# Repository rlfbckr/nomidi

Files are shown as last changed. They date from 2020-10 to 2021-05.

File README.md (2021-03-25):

# NOMIDI
**A [OSC](http://opensoundcontrol.org/) based performance controller**

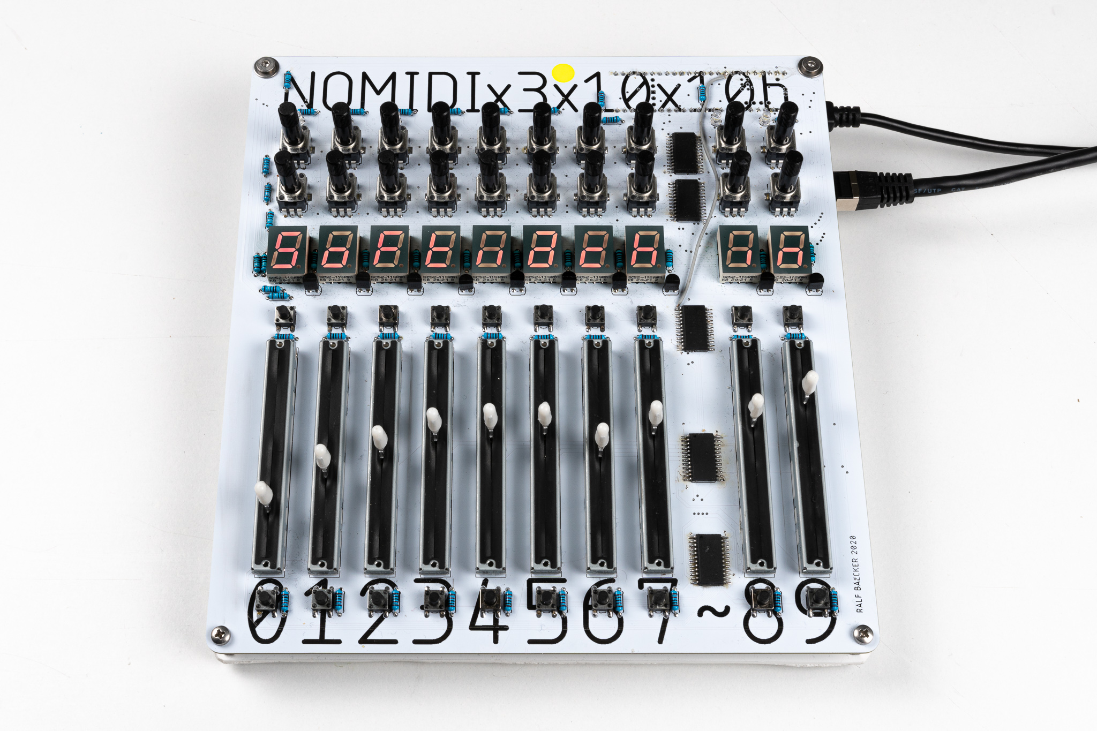
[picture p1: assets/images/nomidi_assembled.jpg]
NOMIDI Assembled


I build this controller out of frustration that [MIDI controllers](https://en.wikipedia.org/wiki/MIDI_controller) are still using only 7 bit resolution. **NOMIDI** is a OSC based controller with 10 channels each 10bit (12 or 14 bit should be possible as well) resolution for the sliders and knobs. The controller is based on a Teensy 4.1 microcontroller including a high speed ethernet port to broadcast and receive OSC to and from different nodes in the network.
 
**PLEAYSE NOTE:** NOMIDI is OSC based in cannot be used in an "MIDI Environment". I can send/reicive only signals form OSC enabled Software and Hardware. e.g. MaxMSP, Supercollider, PureData, Processing, OpenFrameworks, monome norns, Abelton Live and many more.

## Control elements
* inputs:
  - 10 x 2 knobs (potentiometer ALPS)
  - 10 x 2 pushbuttons
  - 10 x 1 slider (potentiometer 6mm ALPS)
* outputs: 
  - 10 x 1 seven-segment element (13,5mm)
  - 10 x 1 white led (3mm)

## Interface / Connection
- USB SlipSerial
**or**
- Ethernet

## PCB (Printed circuit board)
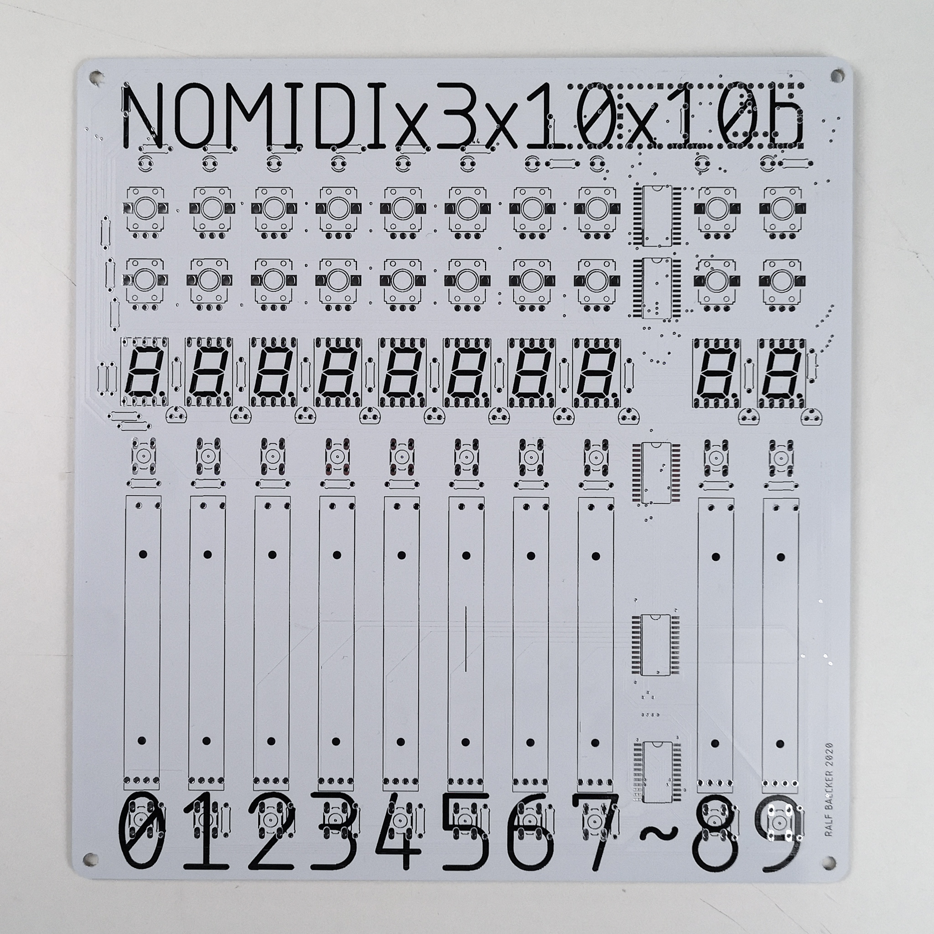
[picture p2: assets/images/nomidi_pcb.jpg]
NOMIDI PCB


## Software
*For flashing the firmware on the Teensy board these software compnents are needed:*

- Arduino IDE (Version 1.8.13) [(download)](https://www.arduino.cc/en/software)
- Teensyduino (Version 1.53) [(download)](https://www.pjrc.com/teensy/td_download.html)

## Required Arduino libraries
- OSCBundle  *[install via package manager]*
- Chrono  *[install via package manager]*
- MUX74HC4067 *[install via package manager]*
- SevSeg ( Seven Segment Multiplexing Library ) *[modefied version included in firmware sketch]*
- NativeEthernet ( Teensy 4.1 ) *[comes with teensyduino]*

## Bill of Materials
[BOM](https://docs.google.com/spreadsheets/d/1EoTag_wGxFKfiME3yydL2qvFMf1TQeLivOXvCBYUS_A/edit#gid=0)

## Firmware configuration

NOMIDI can communicate ether via *Ethernet* oder *Serial* (OSC over SLIPSerial). edit **firmware/nomidi_firmware/config.h**  

### Use Serial ( OSC over SLIP Serial) for communication:
```
#define USE_SLIP_SERIAL
```

### Use Ethernet ( OSC over UDP) for communication:
```
#define USE_ETHERNET

static byte mac[] = { 0xDE, 0xAD, 0xBE, 0xEF, 0xFC, 0x88}; // hardware addres of your device
static IPAddress myIP(10, 0, 0, 123); // ip address of the controller
static IPAddress serverIP(10, 0, 0, 3); // ip addres of your laptop
static int serverPort = 9013;
static int incommingPort = 10013;

```

## Teensy Settings
```
Borad:      Teensy 4.1
USB Type:   USB Serial
CPU Speed:  600 Mhz
```

## OSC messages

### NOMDI -> software

Potentiometer 1 (top row)
```
/nm/p0 [0-4095] [0-4095] [0-4095] [0-4095] [0-4095] [0-4095] [0-4095] [0-4095] [0-4095] [0-4095]
```
Potentiometer 0 (bottom row)
```
/nm/p1 [0-4095] [0-4095] [0-4095] [0-4095] [0-4095] [0-4095] [0-4095] [0-4095] [0-4095] [0-4095]
```
Button 1 (top row)
```
/nm/p1 [0/1] [0/1] [0/1] [0/1] [0/1] [0/1] [0/1] [0/1] [0/1] [0/1]
```
Fader
```
/nm/f [0-4095] [0-4095] [0-4095] [0-4095] [0-4095] [0-4095] [0-4095] [0-4095] [0-4095] [0-4095]
```
Button 0 (bottom row)
```
/nm/p0 [0/1] [0/1] [0/1] [0/1] [0/1] [0/1] [0/1] [0/1] [0/1] [0/1]
```

### software -> NOMIDI
LED (single)
```
/nm/setled <pos 0-9> <brightness 0-100>
```
7Segment (single segment)
```
/nm/set7set <pos 0-9> <character>
```

7Segment (all segments)
```
/nm/set7segall <character> <character> <character> <character> <character> <character> <character> <character> <character> <character>
```

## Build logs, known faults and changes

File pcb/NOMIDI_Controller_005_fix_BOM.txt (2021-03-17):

Partlist exported from C:/local/projekte/nomidi/eagle/NOMIDI_Controller_005_fix.sch at 2021-03-17 19:26

Part Value              Device             Package     Description                       MF MPN      OC_FARNELL OC_NEWARK POPULARITY SPICEPREFIX
D0                      7SEG-CK            7SEG-13     7-segment DISPLAY                                                  3                     
D1                      7SEG-CK            7SEG-13     7-segment DISPLAY                                                  3                     
D2                      7SEG-CK            7SEG-13     7-segment DISPLAY                                                  3                     
D3                      7SEG-CK            7SEG-13     7-segment DISPLAY                                                  3                     
D4                      7SEG-CK            7SEG-13     7-segment DISPLAY                                                  3                     
D5                      7SEG-CK            7SEG-13     7-segment DISPLAY                                                  3                     
D6                      7SEG-CK            7SEG-13     7-segment DISPLAY                                                  3                     
D7                      7SEG-CK            7SEG-13     7-segment DISPLAY                                                  3                     
D8                      7SEG-CK            7SEG-13     7-segment DISPLAY                                                  3                     
D9                      7SEG-CK            7SEG-13     7-segment DISPLAY                                                  3                     
IC1  4067D              4067D              SO24W       16-channel ANALOG MULTIPLEXER                                      0                     
IC2  4067D              4067D              SO24W       16-channel ANALOG MULTIPLEXER                                      0                     
IC3  4067D              4067D              SO24W       16-channel ANALOG MULTIPLEXER                                      0                     
IC4  4067D              4067D              SO24W       16-channel ANALOG MULTIPLEXER                                      0                     
IC5  4067D              4067D              SO24W       16-channel ANALOG MULTIPLEXER                                      0                     
LED0                    LED3MM             LED3MM      LED                                                                97                    
LED1                    LED3MM             LED3MM      LED                                                                97                    
LED2                    LED3MM             LED3MM      LED                                                                97                    
LED3                    LED3MM             LED3MM      LED                                                                97                    
LED4                    LED3MM             LED3MM      LED                                                                97                    
LED5                    LED3MM             LED3MM      LED                                                                97                    
LED6                    LED3MM             LED3MM      LED                                                                97                    
LED7                    LED3MM             LED3MM      LED                                                                97                    
LED8                    LED3MM             LED3MM      LED                                                                97                    
LED9                    LED3MM             LED3MM      LED                                                                97                    
M0   SLIDEPOT-ALPS-60MM SLIDEPOT-ALPS-60MM RS6011SP600                                                                                          
M1   SLIDEPOT-ALPS-60MM SLIDEPOT-ALPS-60MM RS6011SP600                                                                                          
MS0                     10-XX              B3F-10XX    OMRON SWITCH                         B3F-1000 176432     36M3542   72                    
MS1                     10-XX              B3F-10XX    OMRON SWITCH                         B3F-1000 176432     36M3542   72                    
MS2                     10-XX              B3F-10XX    OMRON SWITCH                         B3F-1000 176432     36M3542   72                    
MS3                     10-XX              B3F-10XX    OMRON SWITCH                         B3F-1000 176432     36M3542   72                    
MS4                     10-XX              B3F-10XX    OMRON SWITCH                         B3F-1000 176432     36M3542   72                    
MS5                     10-XX              B3F-10XX    OMRON SWITCH                         B3F-1000 176432     36M3542   72                    
MS6                     10-XX              B3F-10XX    OMRON SWITCH                         B3F-1000 176432     36M3542   72                    
MS7                     10-XX              B3F-10XX    OMRON SWITCH                         B3F-1000 176432     36M3542   72                    
MS8                     10-XX              B3F-10XX    OMRON SWITCH                         B3F-1000 176432     36M3542   72                    
MS9                     10-XX              B3F-10XX    OMRON SWITCH                         B3F-1000 176432     36M3542   72                    
P0_0 US-EVUF3A          US-EVUF3A          EVUF        9 mm Square Rotary Potentiometers                                  0                     
P0_1 US-EVUF3A          US-EVUF3A          EVUF        9 mm Square Rotary Potentiometers                                  0                     
P0_2 US-EVUF3A          US-EVUF3A          EVUF        9 mm Square Rotary Potentiometers                                  0                     
P0_3 US-EVUF3A          US-EVUF3A          EVUF        9 mm Square Rotary Potentiometers                                  0                     
P0_4 US-EVUF3A          US-EVUF3A          EVUF        9 mm Square Rotary Potentiometers                                  0                     
P0_5 US-EVUF3A          US-EVUF3A          EVUF        9 mm Square Rotary Potentiometers                                  0                     
P0_6 US-EVUF3A          US-EVUF3A          EVUF        9 mm Square Rotary Potentiometers                                  0                     
P0_7 US-EVUF3A          US-EVUF3A          EVUF        9 mm Square Rotary Potentiometers                                  0                     
P0_8 US-EVUF3A          US-EVUF3A          EVUF        9 mm Square Rotary Potentiometers                                  0                     
P0_9 US-EVUF3A          US-EVUF3A          EVUF        9 mm Square Rotary Potentiometers                                  0                     
P1_0 US-EVUF3A          US-EVUF3A          EVUF        9 mm Square Rotary Potentiometers                                  0                     
P1_1 US-EVUF3A          US-EVUF3A          EVUF        9 mm Square Rotary Potentiometers                                  0                     
P1_2 US-EVUF3A          US-EVUF3A          EVUF        9 mm Square Rotary Potentiometers                                  0                     
P1_3 US-EVUF3A          US-EVUF3A          EVUF        9 mm Square Rotary Potentiometers                                  0                     
P1_4 US-EVUF3A          US-EVUF3A          EVUF        9 mm Square Rotary Potentiometers                                  0                     
P1_5 US-EVUF3A          US-EVUF3A          EVUF        9 mm Square Rotary Potentiometers                                  0                     
P1_6 US-EVUF3A          US-EVUF3A          EVUF        9 mm Square Rotary Potentiometers                                  0                     
P1_7 US-EVUF3A          US-EVUF3A          EVUF        9 mm Square Rotary Potentiometers                                  0                     
P1_8 US-EVUF3A          US-EVUF3A          EVUF        9 mm Square Rotary Potentiometers                                  0                     
P1_9 US-EVUF3A          US-EVUF3A          EVUF        9 mm Square Rotary Potentiometers                                  0                     
R1   10K                R-EU_0207/7        0207/7      RESISTOR, European symbol                                          46         R          
R2   10K                R-EU_0207/7        0207/7      RESISTOR, European symbol                                          46         R          
R3   10K                R-EU_0207/7        0207/7      RESISTOR, European symbol                                          46         R          
R4   10K                R-EU_0207/7        0207/7      RESISTOR, European symbol                                          46         R          
R5   10K                R-EU_0207/7        0207/7      RESISTOR, European symbol                                          46         R          
R6   10K                R-EU_0207/7        0207/7      RESISTOR, European symbol                                          46         R          
R7   10K                R-EU_0207/7        0207/7      RESISTOR, European symbol                                          46         R          
R8   10K                R-EU_0207/7        0207/7      RESISTOR, European symbol                                          46         R          
R9   10K                R-EU_0207/7        0207/7      RESISTOR, European symbol                                          46         R          
R10  10K                R-EU_0207/7        0207/7      RESISTOR, European symbol                                          46         R          
R11  4k7                R-EU_0207/7        0207/7      RESISTOR, European symbol                                          46         R          
R12  4k7                R-EU_0207/7        0207/7      RESISTOR, European symbol                                          46         R          
R13  4k7                R-EU_0207/7        0207/7      RESISTOR, European symbol                                          46         R          
R14  4k7                R-EU_0207/7        0207/7      RESISTOR, European symbol                                          46         R          
R15  4k7                R-EU_0207/7        0207/7      RESISTOR, European symbol                                          46         R          
R16  1 OHM              R-EU_0207/7        0207/7      RESISTOR, European symbol                                          46         R          
R17  1 OHM              R-EU_0207/7        0207/7      RESISTOR, European symbol                                          46         R          
R18                     R-EU_0207/7        0207/7      RESISTOR, European symbol                                          46         R          
R19  1 OHM              R-EU_0207/7        0207/7      RESISTOR, European symbol                                          46         R          
R20  1 OHM              R-EU_0207/7        0207/7      RESISTOR, European symbol                                          46         R          
R21                     R-EU_0207/7        0207/7      RESISTOR, European symbol                                          46         R          
R22  1 OHM              R-EU_0207/7        0207/7      RESISTOR, European symbol                                          46         R          
R23  1 OHM              R-EU_0207/7        0207/7      RESISTOR, European symbol                                          46         R          
R24  4k7                R-EU_0207/7        0207/7      RESISTOR, European symbol                                          46         R          
R25  4k7                R-EU_0207/7        0207/7      RESISTOR, European symbol                                          46         R          
R26  4k7                R-EU_0207/7        0207/7      RESISTOR, European symbol                                          46         R          
R27  4k7                R-EU_0207/7        0207/7      RESISTOR, European symbol                                          46         R          
R28  4k7                R-EU_0207/7        0207/7      RESISTOR, European symbol                                          46         R          
R29  10k                R-EU_0207/7        0207/7      RESISTOR, European symbol                                          46         R          
R30  10k                R-EU_0207/7        0207/7      RESISTOR, European symbol                                          46         R          
R31  10k                R-EU_0207/7        0207/7      RESISTOR, European symbol                                          46         R          
R32  10k                R-EU_0207/7        0207/7      RESISTOR, European symbol                                          46         R          
R33  10k                R-EU_0207/7        0207/7      RESISTOR, European symbol                                          46         R          
R34  10k                R-EU_0207/7        0207/7      RESISTOR, European symbol                                          46         R          
R35  10k                R-EU_0207/7        0207/7      RESISTOR, European symbol                                          46         R          
R36  10k                R-EU_0207/7        0207/7      RESISTOR, European symbol                                          46         R          
R37  10k                R-EU_0207/7        0207/7      RESISTOR, European symbol                                          46         R          
R38  10k                R-EU_0207/7        0207/7      RESISTOR, European symbol                                          46         R          
R39  220                R-EU_0207/7        0207/7      RESISTOR, European symbol                                          46         R          
R40  220                R-EU_0207/7        0207/7      RESISTOR, European symbol                                          46         R          
R41  220                R-EU_0207/7        0207/7      RESISTOR, European symbol                                          46         R          
R42  220                R-EU_0207/7        0207/7      RESISTOR, European symbol                                          46         R          
R43  220                R-EU_0207/7        0207/7      RESISTOR, European symbol                                          46         R          
R44  220                R-EU_0207/7        0207/7      RESISTOR, European symbol                                          46         R          
R45  220                R-EU_0207/7        0207/7      RESISTOR, European symbol                                          46         R          
R46  220                R-EU_0207/7        0207/7      RESISTOR, European symbol                                          46         R          
R47  220                R-EU_0207/7        0207/7      RESISTOR, European symbol                                          46         R          
R48  220                R-EU_0207/7        0207/7      RESISTOR, European symbol                                          46         R          
S0   SLIDEPOT-ALPS-60MM SLIDEPOT-ALPS-60MM RS6011SP600                                                                                          
S1   SLIDEPOT-ALPS-60MM SLIDEPOT-ALPS-60MM RS6011SP600                                                                                          
S2   SLIDEPOT-ALPS-60MM SLIDEPOT-ALPS-60MM RS6011SP600                                                                                          
S3   SLIDEPOT-ALPS-60MM SLIDEPOT-ALPS-60MM RS6011SP600                                                                                          
S4   SLIDEPOT-ALPS-60MM SLIDEPOT-ALPS-60MM RS6011SP600                                                                                          
S5   SLIDEPOT-ALPS-60MM SLIDEPOT-ALPS-60MM RS6011SP600                                                                                          
S6   SLIDEPOT-ALPS-60MM SLIDEPOT-ALPS-60MM RS6011SP600                                                                                          
S7   SLIDEPOT-ALPS-60MM SLIDEPOT-ALPS-60MM RS6011SP600                                                                                          
SW0                     10-XX              B3F-10XX    OMRON SWITCH                         B3F-1000 176432     36M3542   72                    
SW1                     10-XX              B3F-10XX    OMRON SWITCH                         B3F-1000 176432     36M3542   72                    
SW2                     10-XX              B3F-10XX    OMRON SWITCH                         B3F-1000 176432     36M3542   72                    
SW3                     10-XX              B3F-10XX    OMRON SWITCH                         B3F-1000 176432     36M3542   72                    
SW4                     10-XX              B3F-10XX    OMRON SWITCH                         B3F-1000 176432     36M3542   72                    
SW5                     10-XX              B3F-10XX    OMRON SWITCH                         B3F-1000 176432     36M3542   72                    
SW6                     10-XX              B3F-10XX    OMRON SWITCH                         B3F-1000 176432     36M3542   72                    
SW7                     10-XX              B3F-10XX    OMRON SWITCH                         B3F-1000 176432     36M3542   72                    
SW8                     10-XX              B3F-10XX    OMRON SWITCH                         B3F-1000 176432     36M3542   72                    
SW9                     10-XX              B3F-10XX    OMRON SWITCH                         B3F-1000 176432     36M3542   72                    
T1   BC547              BC547              TO92        NPN TRANSISTOR                                                     0                     
T2   BC547              BC547              TO92        NPN TRANSISTOR                                                     0                     
T3   BC547              BC547              TO92        NPN TRANSISTOR                                                     0                     
T4   BC547              BC547              TO92        NPN TRANSISTOR                                                     0                     
T5   BC547              BC547              TO92        NPN TRANSISTOR                                                     0                     
T6   BC547              BC547              TO92        NPN TRANSISTOR                                                     0                     
T7   BC547              BC547              TO92        NPN TRANSISTOR                                                     0                     
T8   BC547              BC547              TO92        NPN TRANSISTOR                                                     0                     
T9   BC547              BC547              TO92        NPN TRANSISTOR                                                     0                     
T10  BC547              BC547              TO92        NPN TRANSISTOR                                                     0                     
U$1  TEENSY41           TEENSY41           TEENSY41

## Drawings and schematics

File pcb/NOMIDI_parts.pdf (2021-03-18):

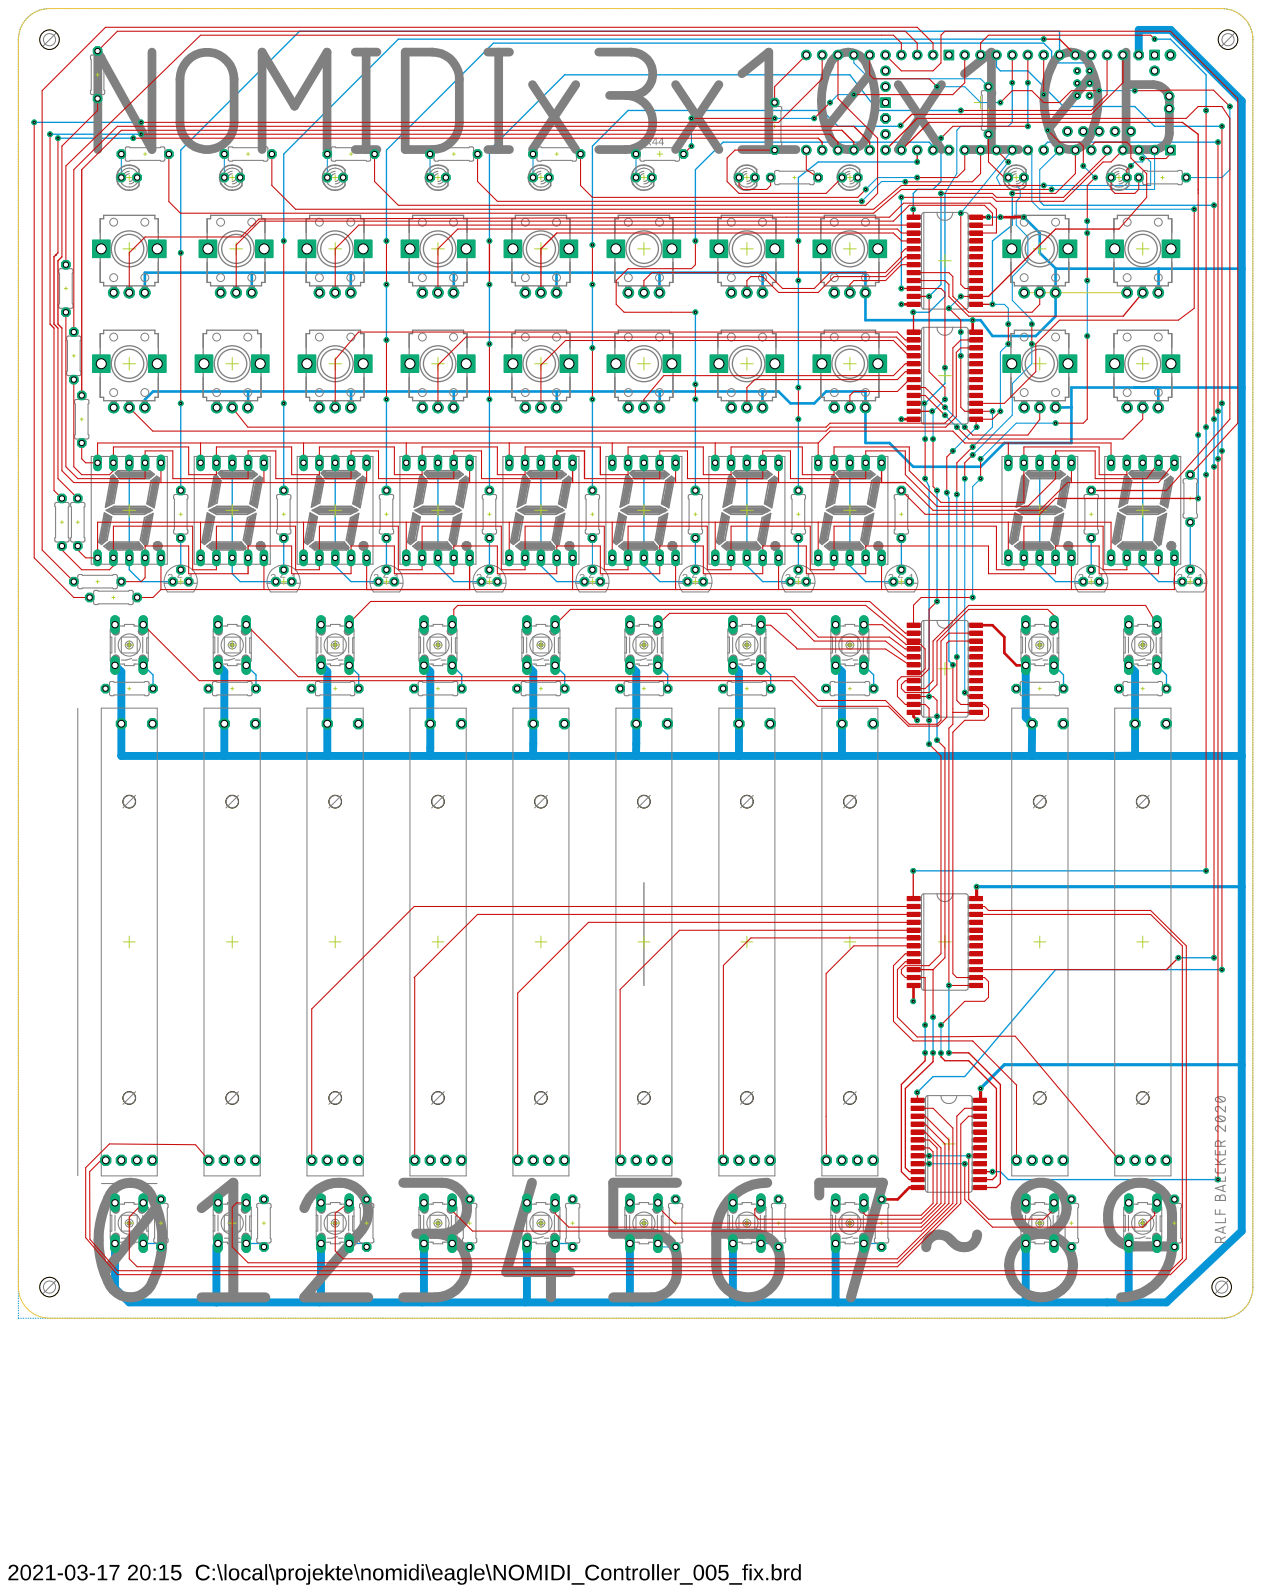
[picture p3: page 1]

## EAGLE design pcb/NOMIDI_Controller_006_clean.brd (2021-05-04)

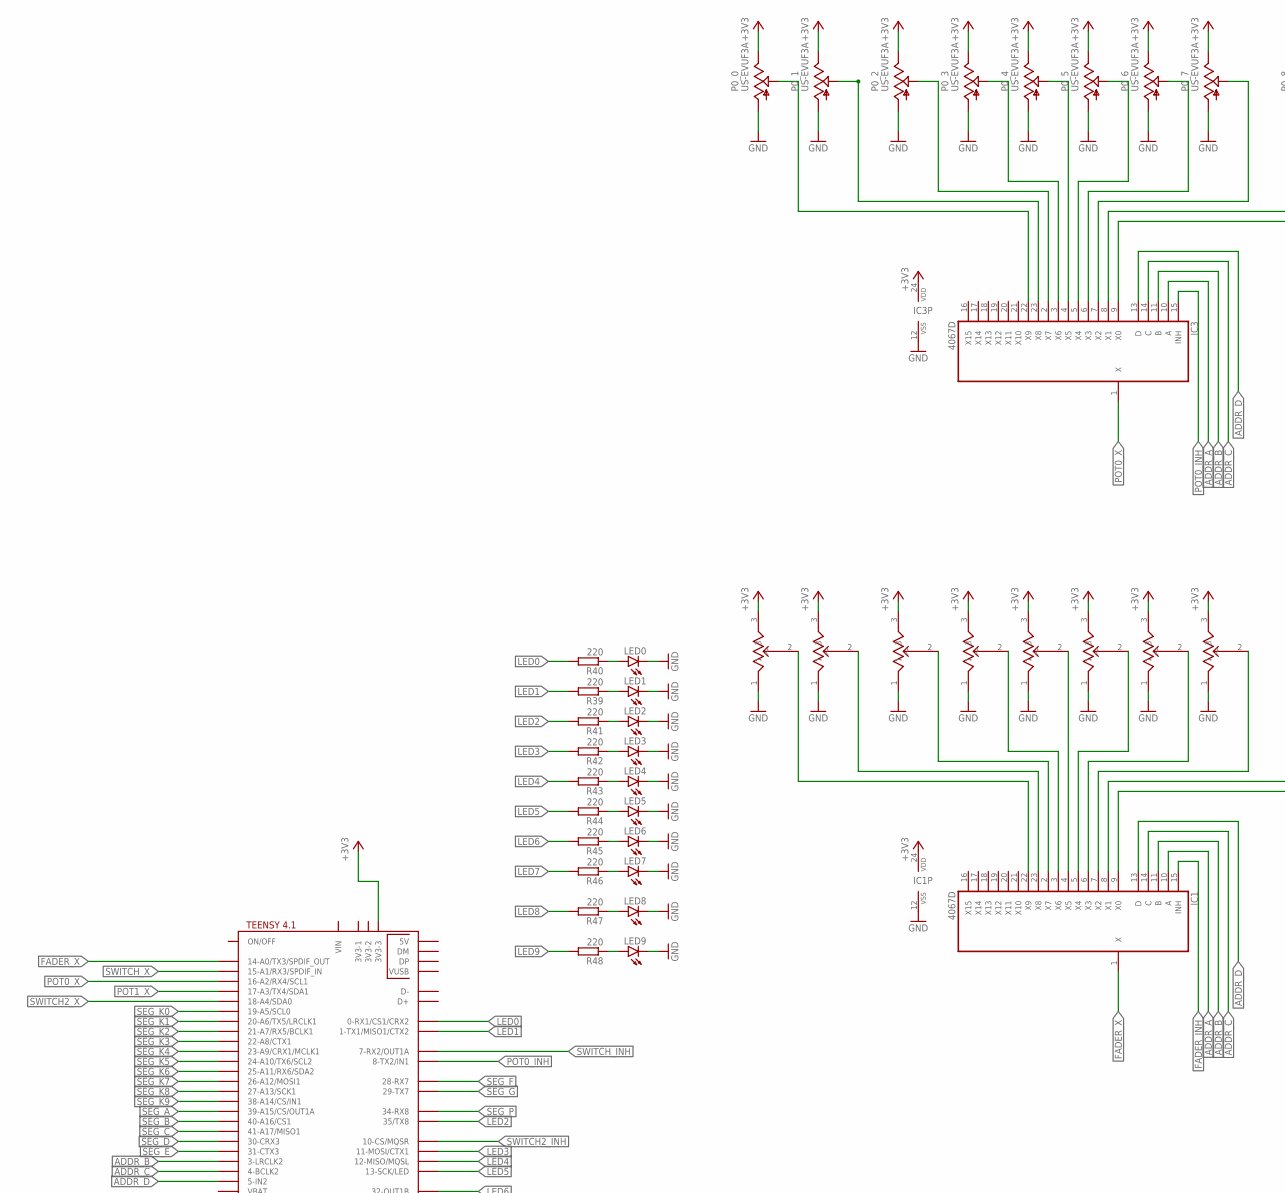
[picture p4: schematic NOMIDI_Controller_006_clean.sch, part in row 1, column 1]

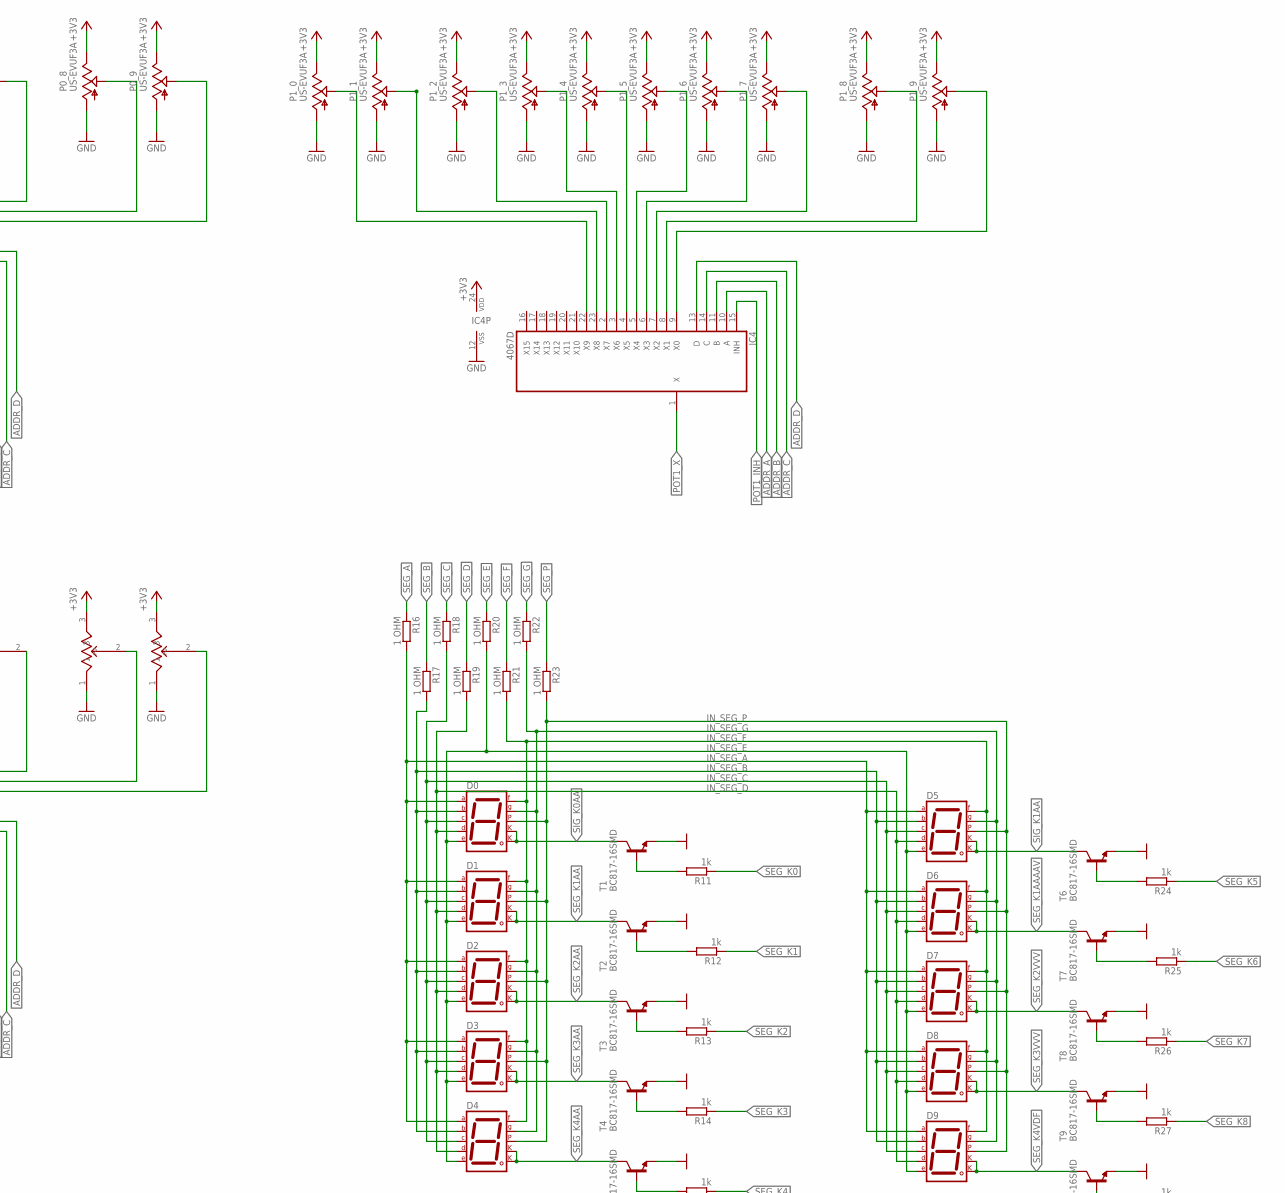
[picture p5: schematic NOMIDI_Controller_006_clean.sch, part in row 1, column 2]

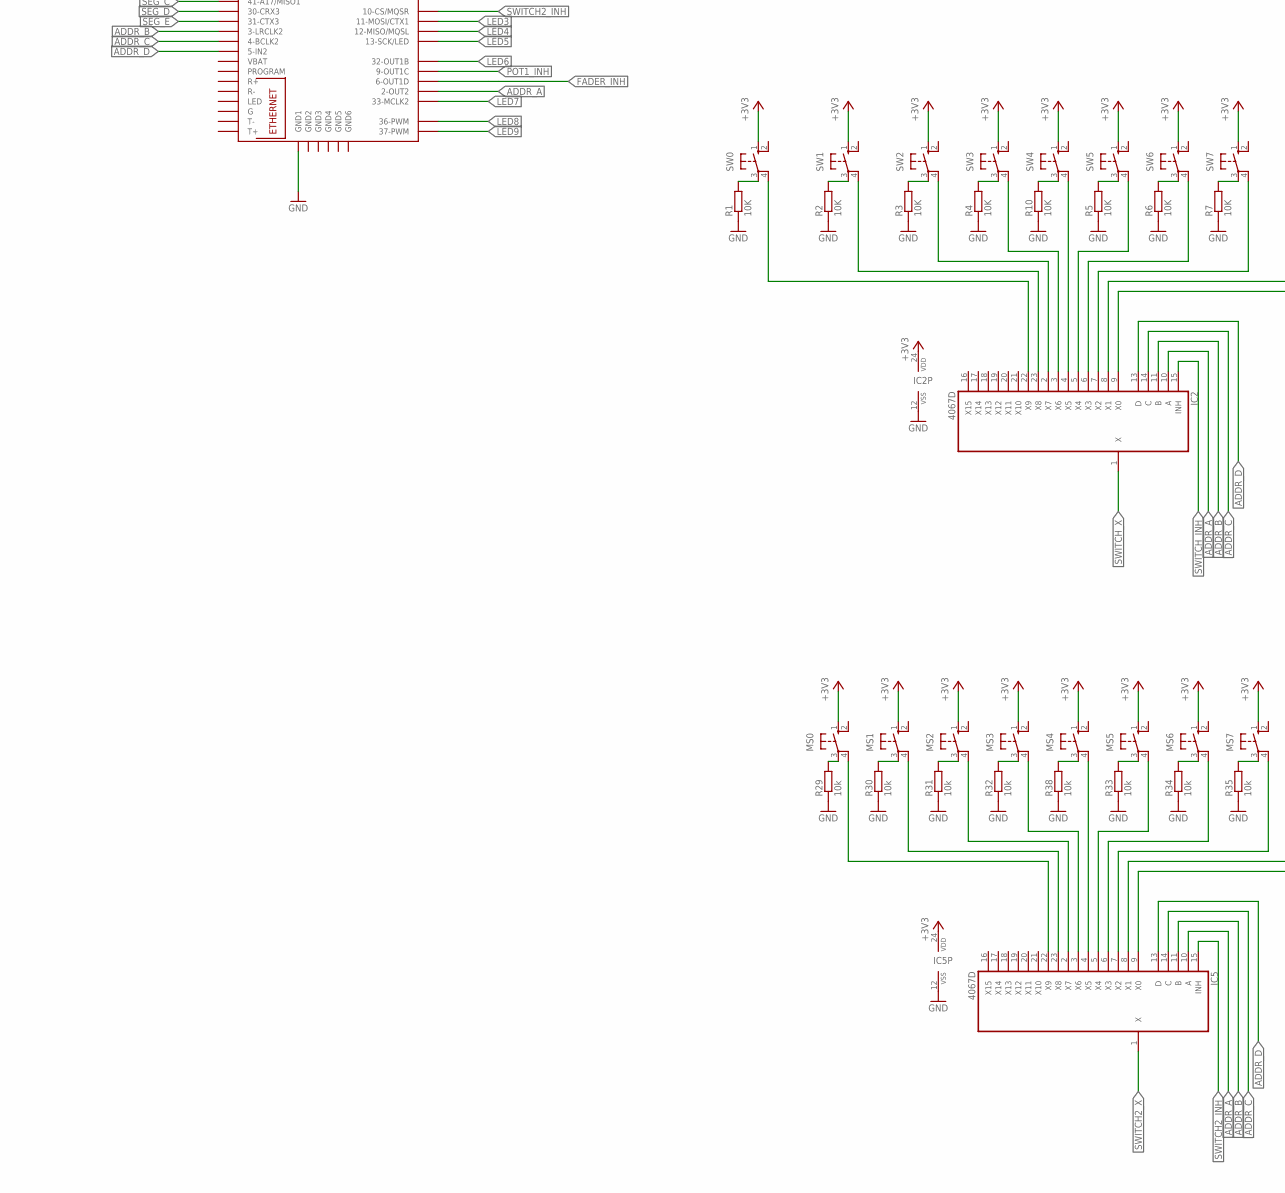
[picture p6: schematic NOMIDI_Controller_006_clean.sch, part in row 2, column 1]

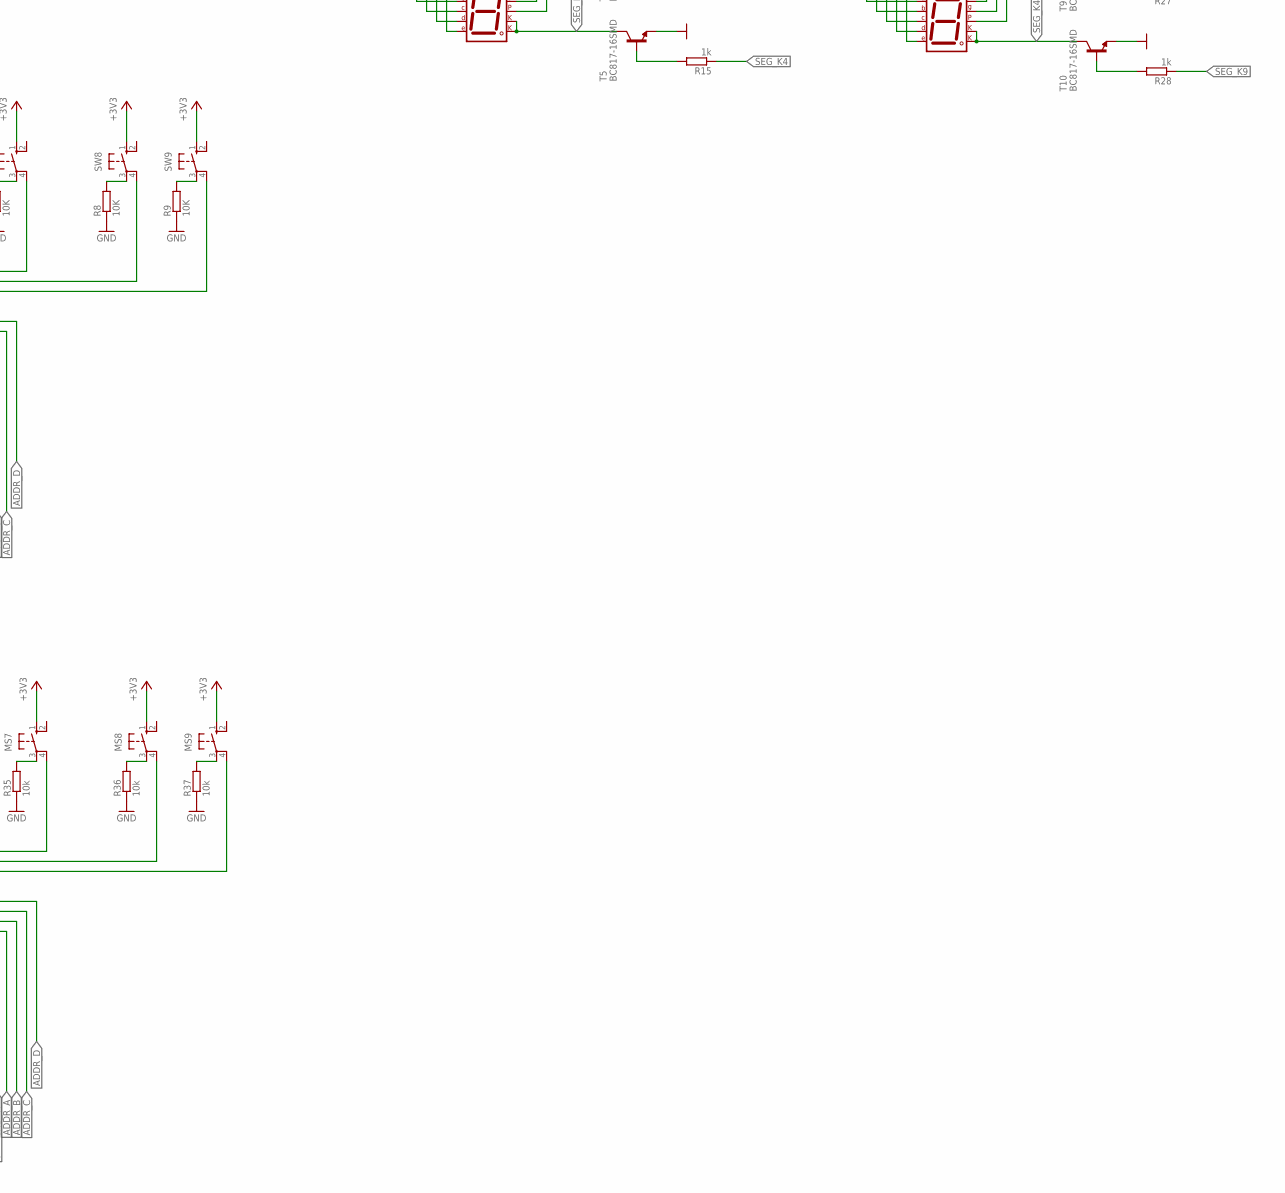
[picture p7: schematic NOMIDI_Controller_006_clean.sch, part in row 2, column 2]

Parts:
D0, D1, D2, D3, D4, D5, D6, D7, D8, D9: 7SEG-CK; 7SEG-13
IC1, IC2, IC3, IC4, IC5: 4067D; SO24W
LED0, LED1, LED2, LED3, LED4, LED5, LED6, LED7, LED8, LED9: LED3MM
M0, M1: SLIDEPOT-ALPS-60MM; RS6011SP600
MS0, MS1, MS2, MS3, MS4, MS5, MS6, MS7, MS8, MS9: 10-XX; B3F-10XX
P0_0, P0_1, P0_2, P0_3, P0_4, P0_5, P0_6, P0_7, P0_8, P0_9, P1_0, P1_1, P1_2, P1_3, P1_4, P1_5, P1_6, P1_7, P1_8, P1_9: US-EVUF3A; EVUF
R1, R2, R3, R4, R5, R6, R7, R8, R9, R10: 10K; 0207/7
R11, R12, R13, R14, R15, R24, R25, R26, R27, R28: 1k; 0207/7
R16, R17, R18, R19, R20, R21, R22, R23: 1 OHM; 0207/7
R29, R30, R31, R32, R33, R34, R35, R36, R37, R38: 10k; 0207/7
R39, R40, R41, R42, R43, R44, R45, R46, R47, R48: 220; 0207/7
S0, S1, S2, S3, S4, S5, S6, S7: SLIDEPOT-ALPS-60MM; RS6011SP600
SW0, SW1, SW2, SW3, SW4, SW5, SW6, SW7, SW8, SW9: 10-XX; B3F-10XX
T1, T2, T3, T4, T5, T6, T7, T8, T9, T10: BC817-16SMD; SOT23-BEC
U$1: TEENSY41

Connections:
+3V3: IC1.24 (VDD), IC2.24 (VDD), IC3.24 (VDD), IC4.24 (VDD), IC5.24 (VDD), M0.3, M1.3, MS0.1 (S), MS1.1 (S), MS2.1 (S), MS3.1 (S), MS4.1 (S), MS5.1 (S), MS6.1 (S), MS7.1 (S), MS8.1 (S), MS9.1 (S), P0_0.3 (E), P0_1.3 (E), P0_2.3 (E), P0_3.3 (E), P0_4.3 (E), P0_5.3 (E), P0_6.3 (E), P0_7.3 (E), P0_8.3 (E), P0_9.3 (E), P1_0.3 (E), P1_1.3 (E), P1_2.3 (E), P1_3.3 (E), P1_4.3 (E), P1_5.3 (E), P1_6.3 (E), P1_7.3 (E), P1_8.3 (E), P1_9.3 (E), S0.3, S1.3, S2.3, S3.3, S4.3, S5.3, S6.3, S7.3, SW0.1 (S), SW1.1 (S), SW2.1 (S), SW3.1 (S), SW4.1 (S), SW5.1 (S), SW6.1 (S), SW7.1 (S), SW8.1 (S), SW9.1 (S), U$1.3V3-3
ADDR_A: IC1.10 (A), IC2.10 (A), IC3.10 (A), IC4.10 (A), IC5.10 (A), U$1.2-OUT2
ADDR_B: IC1.11 (B), IC2.11 (B), IC3.11 (B), IC4.11 (B), IC5.11 (B), U$1.3-LRCLK2
ADDR_C: IC1.14 (C), IC2.14 (C), IC3.14 (C), IC4.14 (C), IC5.14 (C), U$1.4-BCLK2
ADDR_D: IC1.13 (D), IC2.13 (D), IC3.13 (D), IC4.13 (D), IC5.13 (D), U$1.5-IN2
FADER_INH: IC1.15 (INH), U$1.6-OUT1D
FADER_X: IC1.1 (X), U$1.14-A0/TX3/SPDIF_OUT
GND: IC1.12 (VSS), IC2.12 (VSS), IC3.12 (VSS), IC4.12 (VSS), IC5.12 (VSS), LED0.K (C), LED1.K (C), LED2.K (C), LED3.K (C), LED4.K (C), LED5.K (C), LED6.K (C), LED7.K (C), LED8.K (C), LED9.K (C), M0.1, M1.1, P0_0.1 (A), P0_1.1 (A), P0_2.1 (A), P0_3.1 (A), P0_4.1 (A), P0_5.1 (A), P0_6.1 (A), P0_7.1 (A), P0_8.1 (A), P0_9.1 (A), P1_0.1 (A), P1_1.1 (A), P1_2.1 (A), P1_3.1 (A), P1_4.1 (A), P1_5.1 (A), P1_6.1 (A), P1_7.1 (A), P1_8.1 (A), P1_9.1 (A), R1.1, R2.1, R3.1, R4.1, R5.1, R6.1, R7.1, R8.1, R9.1, R10.1, R29.1, R30.1, R31.1, R32.1, R33.1, R34.1, R35.1, R36.1, R37.1, R38.1, S0.1, S1.1, S2.1, S3.1, S4.1, S5.1, S6.1, S7.1, T1.E, T2.E, T3.E, T4.E, T5.E, T6.E, T7.E, T8.E, T9.E, T10.E, U$1.GND1
IN_SEG_A: D0.7 (A), D1.7 (A), D2.7 (A), D3.7 (A), D4.7 (A), D5.7 (A), D6.7 (A), D7.7 (A), D8.7 (A), D9.7 (A), R16.2
IN_SEG_B: D0.6 (B), D1.6 (B), D2.6 (B), D3.6 (B), D4.6 (B), D5.6 (B), D6.6 (B), D7.6 (B), D8.6 (B), D9.6 (B), R17.2
IN_SEG_C: D0.4 (C), D1.4 (C), D2.4 (C), D3.4 (C), D4.4 (C), D5.4 (C), D6.4 (C), D7.4 (C), D8.4 (C), D9.4 (C), R18.2
IN_SEG_D: D0.2 (D), D1.2 (D), D2.2 (D), D3.2 (D), D4.2 (D), D5.2 (D), D6.2 (D), D7.2 (D), D8.2 (D), D9.2 (D), R19.2
IN_SEG_E: D0.1 (E), D1.1 (E), D2.1 (E), D3.1 (E), D4.1 (E), D5.1 (E), D6.1 (E), D7.1 (E), D8.1 (E), D9.1 (E), R20.2
IN_SEG_F: D0.9 (F), D1.9 (F), D2.9 (F), D3.9 (F), D4.9 (F), D5.9 (F), D6.9 (F), D7.9 (F), D8.9 (F), D9.9 (F), R21.2
IN_SEG_G: D0.10 (G), D1.10 (G), D2.10 (G), D3.10 (G), D4.10 (G), D5.10 (G), D6.10 (G), D7.10 (G), D8.10 (G), D9.10 (G), R22.2
IN_SEG_P: D0.5 (DP), D1.5 (DP), D2.5 (DP), D3.5 (DP), D4.5 (DP), D5.5 (DP), D6.5 (DP), D7.5 (DP), D8.5 (DP), D9.5 (DP), R23.2
LED0: R40.2, U$1.0-RX1/CS1/CRX2
LED1: R39.2, U$1.1-TX1/MISO1/CTX2
LED2: R41.2, U$1.35-TX8 (35/TX8)
LED3: R42.2, U$1.11-MOSI/CTX1
LED4: R43.2, U$1.12-MISO/MQSL
LED5: R44.2, U$1.13-SCK/LED
LED6: R45.2, U$1.32-OUT1B
LED7: R46.2, U$1.33-MCLK2
LED8: R47.2, U$1.36-PWM
LED9: R48.2, U$1.37-PWM
unnamed: IC1.22 (X9), S0.2
unnamed: IC1.9 (X0), M1.2
unnamed: IC1.8 (X1), M0.2
unnamed: IC2.9 (X0), SW9.4 (P1)
unnamed: IC1.7 (X2), S7.2
unnamed: IC1.6 (X3), S6.2
unnamed: IC1.5 (X4), S5.2
unnamed: IC1.4 (X5), S4.2
unnamed: IC1.3 (X6), S3.2
unnamed: IC1.2 (X7), S2.2
unnamed: IC1.23 (X8), S1.2
unnamed: IC2.8 (X1), SW8.4 (P1)
unnamed: IC2.7 (X2), SW7.4 (P1)
unnamed: IC2.6 (X3), SW6.4 (P1)
unnamed: IC2.5 (X4), SW5.4 (P1)
unnamed: IC3.9 (X0), P0_9.2 (S)
unnamed: IC2.3 (X6), SW3.4 (P1)
unnamed: IC2.2 (X7), SW2.4 (P1)
unnamed: IC2.23 (X8), SW1.4 (P1)
unnamed: IC2.22 (X9), SW0.4 (P1)
unnamed: R1.2, SW0.3
unnamed: R2.2, SW1.3
unnamed: IC3.8 (X1), P0_8.2 (S)
unnamed: R3.2, SW2.3
unnamed: IC3.7 (X2), P0_7.2 (S)
unnamed: R4.2, SW3.3
unnamed: IC3.6 (X3), P0_6.2 (S)
unnamed: R5.2, SW5.3
unnamed: IC3.5 (X4), P0_5.2 (S)
unnamed: R6.2, SW6.3
unnamed: IC3.4 (X5), P0_4.2 (S)
unnamed: R7.2, SW7.3
unnamed: IC3.3 (X6), P0_3.2 (S)
unnamed: R8.2, SW8.3
unnamed: IC3.2 (X7), P0_2.2 (S)
unnamed: R9.2, SW9.3
unnamed: IC2.4 (X5), SW4.4 (P1)
unnamed: R10.2, SW4.3
unnamed: IC3.23 (X8), P0_1.2 (S)
unnamed: IC3.22 (X9), P0_0.2 (S)
unnamed: IC4.9 (X0), P1_9.2 (S)
unnamed: IC4.8 (X1), P1_8.2 (S)
unnamed: IC4.7 (X2), P1_7.2 (S)
unnamed: IC4.6 (X3), P1_6.2 (S)
unnamed: IC4.5 (X4), P1_5.2 (S)
unnamed: IC4.4 (X5), P1_4.2 (S)
unnamed: IC4.3 (X6), P1_3.2 (S)
unnamed: IC4.2 (X7), P1_2.2 (S)
unnamed: IC4.23 (X8), P1_1.2 (S)
unnamed: IC4.22 (X9), P1_0.2 (S)
unnamed: R11.2, T1.B
unnamed: R12.2, T2.B
unnamed: IC5.9 (X0), MS9.4 (P1)
unnamed: R13.2, T3.B
unnamed: R14.2, T4.B
unnamed: R15.2, T5.B
unnamed: IC5.8 (X1), MS8.4 (P1)
unnamed: IC5.7 (X2), MS7.4 (P1)
unnamed: IC5.6 (X3), MS6.4 (P1)
unnamed: IC5.5 (X4), MS5.4 (P1)
unnamed: IC5.3 (X6), MS3.4 (P1)
unnamed: IC5.2 (X7), MS2.4 (P1)
unnamed: IC5.23 (X8), MS1.4 (P1)
unnamed: R24.2, T6.B
unnamed: R25.2, T7.B
unnamed: R26.2, T8.B
unnamed: R27.2, T9.B
unnamed: R28.2, T10.B
unnamed: IC5.22 (X9), MS0.4 (P1)
unnamed: MS0.3, R29.2
unnamed: MS1.3, R30.2
unnamed: MS2.3, R31.2
unnamed: MS3.3, R32.2
unnamed: MS5.3, R33.2
unnamed: MS6.3, R34.2
unnamed: MS7.3, R35.2
unnamed: MS8.3, R36.2
unnamed: MS9.3, R37.2
unnamed: IC5.4 (X5), MS4.4 (P1)
unnamed: MS4.3, R38.2
unnamed: LED2.A, R41.1
unnamed: LED0.A, R40.1
unnamed: LED3.A, R42.1
unnamed: LED1.A, R39.1
unnamed: LED4.A, R43.1
unnamed: LED5.A, R44.1
unnamed: LED6.A, R45.1
unnamed: LED7.A, R46.1
unnamed: LED8.A, R47.1
unnamed: LED9.A, R48.1
POT0_INH: IC3.15 (INH), U$1.8-TX2/IN1
POT0_X: IC3.1 (X), U$1.16-A2/RX4/SCL1
POT1_INH: IC4.15 (INH), U$1.9-OUT1C
POT1_X: IC4.1 (X), U$1.17-A3/TX4/SDA1
SEG_A: R16.1, U$1.39-A15/CS/OUT1A
SEG_B: R17.1, U$1.40-A16/CS1
SEG_C: R18.1, U$1.41-A17/MISO1
SEG_D: R19.1, U$1.30-CRX3
SEG_E: R20.1, U$1.31-CTX3
SEG_F: R21.1, U$1.28-RX7
SEG_G: R22.1, U$1.29-TX7
SEG_K0: R11.1, U$1.19-A5/SCL0
SEG_K1: R12.1, U$1.20-A6/TX5/LRCLK1
SEG_K1AA: D1.3 (CK1), D1.8 (CK2), T2.C
SEG_K1AAAAV: D6.3 (CK1), D6.8 (CK2), T7.C
SEG_K2: R13.1, U$1.21-A7/RX5/BCLK1
SEG_K2AA: D2.3 (CK1), D2.8 (CK2), T3.C
SEG_K2VVV: D7.3 (CK1), D7.8 (CK2), T8.C
SEG_K3: R14.1, U$1.22-A8/CTX1
SEG_K3AA: D3.3 (CK1), D3.8 (CK2), T4.C
SEG_K3VVV: D8.3 (CK1), D8.8 (CK2), T9.C
SEG_K4: R15.1, U$1.23-A9/CRX1/MCLK1
SEG_K4AA: D4.3 (CK1), D4.8 (CK2), T5.C
SEG_K4VDF: D9.3 (CK1), D9.8 (CK2), T10.C
SEG_K5: R24.1, U$1.24-A10/TX6/SCL2
SEG_K6: R25.1, U$1.25-A11/RX6/SDA2
SEG_K7: R26.1, U$1.26-A12/MOSI1
SEG_K8: R27.1, U$1.27-A13/SCK1
SEG_K9: R28.1, U$1.38-A14/CS/IN1
SEG_P: R23.1, U$1.34-RX8
SIG_K0AA: D0.3 (CK1), D0.8 (CK2), T1.C
SIG_K1AA: D5.3 (CK1), D5.8 (CK2), T6.C
SWITCH2_INH: IC5.15 (INH), U$1.10-CS\MQSR (10-CS/MQSR)
SWITCH2_X: IC5.1 (X), U$1.18-A4/SDA0
SWITCH_INH: IC2.15 (INH), U$1.7-RX2/OUT1A
SWITCH_X: IC2.1 (X), U$1.15-A1/RX3/SPDIF_IN

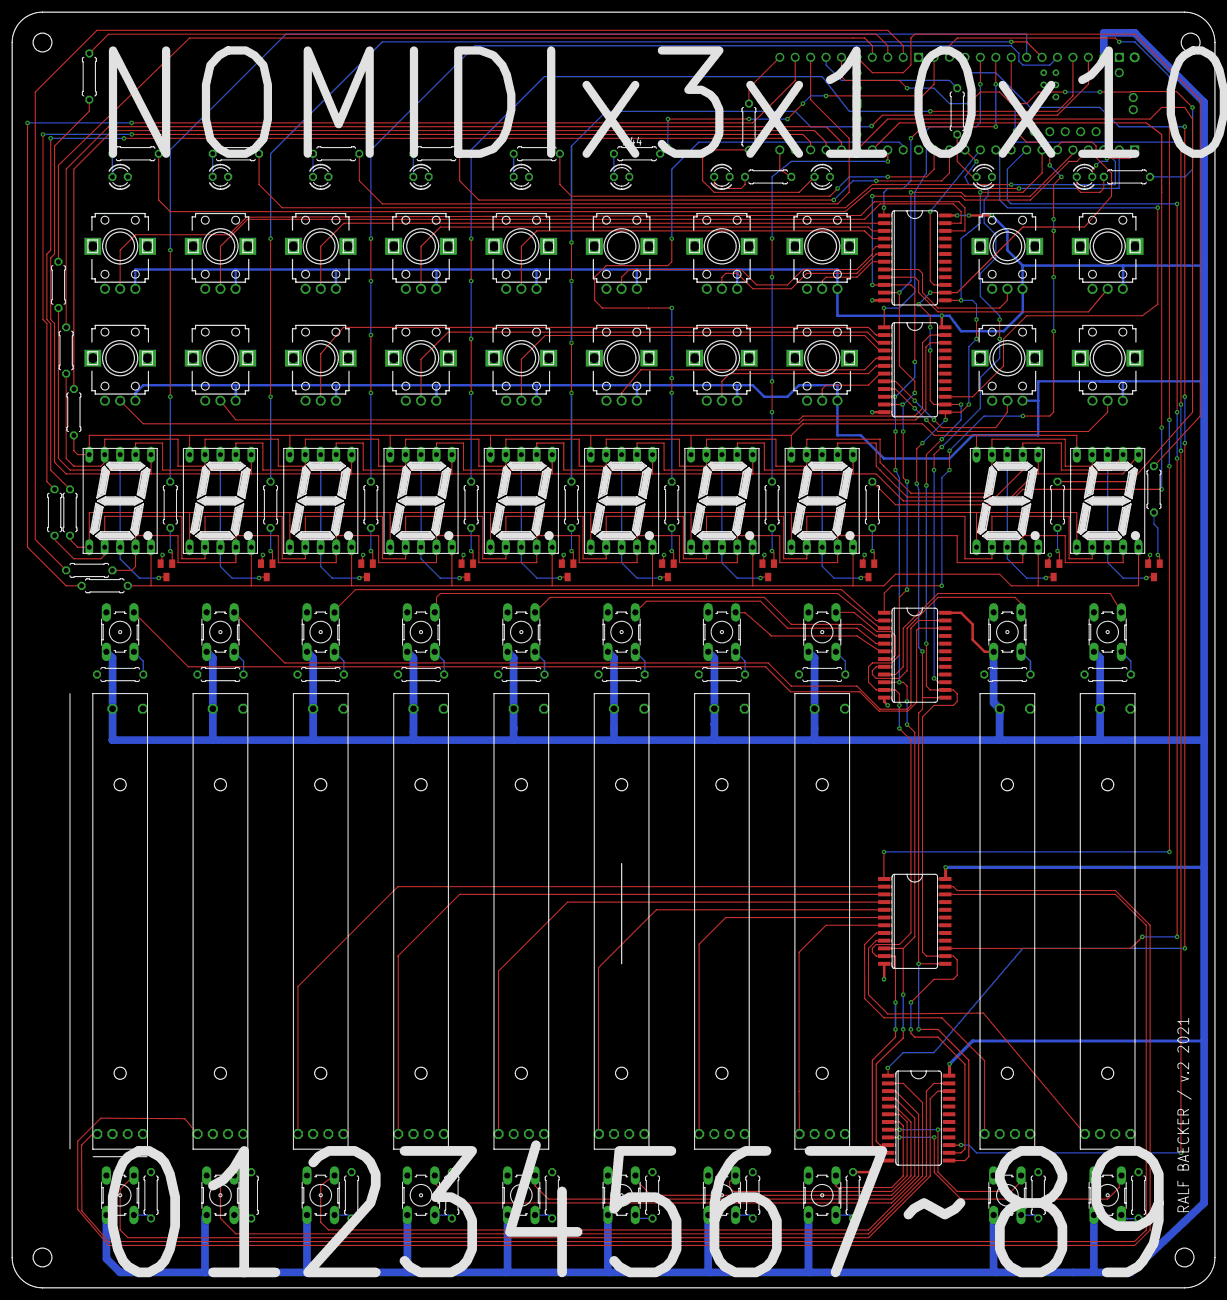
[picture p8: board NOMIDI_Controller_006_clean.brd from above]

Board: 2 copper layers, 198.0 x 210.0 mm, 134 parts (1 on the bottom side), 152 nets.

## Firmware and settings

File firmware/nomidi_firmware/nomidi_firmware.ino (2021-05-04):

#include <Esplora.h>

/*
  This file is part of
  NOMIDI - A OSC based performance controller

  Copyright (c) 2021 by Ralf Baecker <rlfbckr ~AT~ gmail.com>

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
  You should have received a copy of the GNU General Public License
  along with this program.  If not, see <http://www.gnu.org/licenses/>.
*/

#include "nomidi.h"
/*
  Borad:      Teensy 4.1
  USB Type:   USB Serial
  CPU Speed:  600 Mhz
*/


void setup() {
#ifdef USE_SLIP_SERIAL
  SLIPSerial.begin(1000000);
#else
  Serial.begin(115200);
  Serial.print("NOMIDI v");
  Serial.println(  _VERSION_);
#endif


  mux_pot0.signalPin(POT0_X, INPUT, ANALOG);
  mux_pot1.signalPin(POT1_X, INPUT, ANALOG);
  mux_fader.signalPin(FADER_X, INPUT, ANALOG);
  mux_button0.signalPin(BUTTON0_X, INPUT, ANALOG);
  mux_button1.signalPin(BUTTON1_X, INPUT, ANALOG);

  bool resistorsOnSegments = false; // 'false' means resistors are on digit pins
  byte hardwareConfig = N_TRANSISTORS  ; // See README.md for options
  bool updateWithDelays = false; // Default 'false' is Recommended
  bool leadingZeros = false; // Use 'true' if you'd like to keep the leading zeros
  bool disableDecPoint = false; // Use 'true' if your decimal point doesn't exist or isn't connected

  sevseg.begin(hardwareConfig, 10, segCathodePins, segAnodePins, resistorsOnSegments, updateWithDelays, leadingZeros, disableDecPoint);
  sevseg.setBrightness(setup_brighness);
  analogReadResolution(12);
  analogReadAveraging(200); // 100 ok
  initLED();
#ifdef USE_ETHERNET
  initEthernet();
#endif
  updateDisplayTimer.begin(updateSevenSegment, 250);
  softPWMTimer.begin(updateSoftPWM, 100);
}

void loop() {
  if (_SETUPMODE_) {
    setupMode();
  }
  if (readInputsChrono.hasPassed(10) ) {
    readInputsChrono.restart();
    readInputs();
  }
  if (sendOSC.hasPassed(30) ) {
    sendOSC.restart();
    sendInputsOSC();
  }

  drawAnimation();

#ifdef USE_ETHERNET
  readUdpOsc();
#endif

#ifdef USE_SLIP_SERIAL
  readSerialOSC();
#endif

}

#ifdef USE_ETHERNET
void readUdpOsc() {
  OSCMessage msgIn;
  int msg_size;
  if ((msg_size = Udp.parsePacket()) > 0) {
    while (msg_size--)
      msgIn.fill(Udp.read());
    if (!msgIn.hasError()) {
      msgIn.route("/nm/set7seg", OSCset7Seg);
      msgIn.route("/nm/set7segall", OSCset7SegAll);
      msgIn.route("/nm/setled", OSCsetLED);
    }
  }
}
#endif

#ifdef USE_SLIP_SERIAL
void readSerialOSC() {
  if (SLIPSerial.available()) {
    OSCBundle msgIn;

    int size;
    while (!SLIPSerial.endofPacket())
      if ((size = SLIPSerial.available()) > 0) {
        while (size--) msgIn.fill(SLIPSerial.read());
      }
    if (!msgIn.hasError()) {
      msgIn.route("/nm/set7seg", OSCset7Seg);
      msgIn.route("/nm/set7segall", OSCset7SegAll);
      msgIn.route("/nm/setled", OSCsetLED);
      // msgIn.route("/nm/sendall", OSCsendAll);

    }
  }
}
#endif

void action(OSCMessage &msg, int addrOffset) {
  //digitalWrite(ledPins[msg.getInt(0)], HIGH);
  ledIntesity[msg.getInt(0)] = 100;
  delay(100);
  ledIntesity[msg.getInt(0)] = 0;
}

void updateSevenSegment() {
  sevseg.setChars(segmentData);
  sevseg.refreshDisplay();
}

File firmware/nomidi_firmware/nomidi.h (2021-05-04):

/*
  This file is part of
  NOMIDI - A OSC based performance controller

  Copyright (c) 2021 by Ralf Baecker <rlfbckr ~AT~ gmail.com>

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
  You should have received a copy of the GNU General Public License
  along with this program.  If not, see <http://www.gnu.org/licenses/>.
*/

#include <NativeEthernet.h>
#include <NativeEthernetUdp.h>
#include <OSCBundle.h>
#include <Chrono.h>
#include "SevSeg.h"
#include "MUX74HC4067.h"
#include "config.h"
#include "animation.h"

#define _VERSION_ 0.06

boolean _SETUPMODE_ = false;

int setup_pos = 0;
int setup_pos_max = 2;
int setup_brighness = 60;

boolean BUTTON_SWI = false;
boolean BUTTON_PRE = false;
boolean BUTTON_NXT  = false;
boolean BUTTON_SEL = false;


volatile char segmentData[] = "----------";
const byte segCathodePins[] = {19, 20, 21, 22, 23, 24, 25, 26, 27, 38};
const byte segAnodePins[] = {39, 40, 41, 30, 31, 28, 29, 34};


const int ledPins[] = {0, 1, 35, 11, 12, 13, 32, 33, 36, 37};
volatile int ledIntesity[] = { 0, 0, 0, 0, 0, 0, 0, 0, 0, 0};
volatile int softPWMtic = 0;
volatile int softPWMres = 100;

const float inputValueSmoothing = 0.5; // 0.2 ok the smaller the smoother
const float inputValueGain = 1.003;
const int inputValueLowCut = 5;
const int inputValueHighCut = 4090;
const int inputHysteresisMax = 15;
const int inputHysteresisMin = 1; // 1
const int inputHysteresisIntervall = 50;

const int ADDR_A = 2;
const int ADDR_B = 3;
const int ADDR_C = 4;
const int ADDR_D = 5;

const int POT1_X = A3;
const int POT1_INH = 9;
volatile float POT1_RAW[] = { 0 , 0, 0, 0, 0, 0 , 0, 0, 0, 0};
volatile int POT1_VALUES[] = { 0 , 0, 0, 0, 0, 0 , 0, 0, 0, 0};
volatile int POT1_VALUES_LAST[] = { -111 , -111, -111, -111, -111, -111, -111, -111, -111, -111};
volatile int POT1_HYS[] = { inputHysteresisMax, inputHysteresisMax, inputHysteresisMax, inputHysteresisMax, inputHysteresisMax, inputHysteresisMax, inputHysteresisMax, inputHysteresisMax, inputHysteresisMax, inputHysteresisMax };
volatile long POT1_HYS_LAST_CHANGE[] = { 0, 0, 0, 0, 0, 0, 0, 0, 0, 0};

const int POT0_X = A2;
const int POT0_INH = 8;
volatile double POT0_RAW[] = { 0 , 0, 0, 0, 0, 0 , 0, 0, 0, 0};
volatile int POT0_VALUES[] = { 0 , 0, 0, 0, 0, 0 , 0, 0, 0, 0};
volatile int POT0_VALUES_LAST[] = { -111 , -111, -111, -111, 111, 111 , -111, -111, -111, -111};
volatile int POT0_HYS[] = { inputHysteresisMax, inputHysteresisMax, inputHysteresisMax, inputHysteresisMax, inputHysteresisMax, inputHysteresisMax, inputHysteresisMax, inputHysteresisMax, inputHysteresisMax, inputHysteresisMax };
volatile long POT0_HYS_LAST_CHANGE[] = { 0, 0, 0, 0, 0, 0, 0, 0, 0, 0};

const int FADER_X = A0;
const int FADER_INH = 6;
volatile int FADER_VALUES[] = { 0 , 0, 0, 0, 0, 0 , 0, 0, 0, 0};
volatile int FADER_VALUES_LAST[] = { -111 , -111, -111, -111, -111, -111 , -111, -111, -111, -111};
volatile int FADER_HYS[] = { inputHysteresisMax, inputHysteresisMax, inputHysteresisMax, inputHysteresisMax, inputHysteresisMax, inputHysteresisMax, inputHysteresisMax, inputHysteresisMax, inputHysteresisMax, inputHysteresisMax };
volatile long FADER_HYS_LAST_CHANGE[] = { 0, 0, 0, 0, 0, 0, 0, 0, 0, 0};

const int BUTTON0_X = 15;
const int BUTTON0_INH = 7;
volatile int BUTTON0_VALUES_LAST[] = { -1 , -1, -1, -1, -1, -1 , -1, -1, -1, -1};
volatile int BUTTON0_VALUES_LAST_SEND[] = { -1 , -1, -1, -1, -1, -1 , -1, -1, -1, -1};
volatile int BUTTON0_VALUES[] = { 0 , 0, 0, 0, 0, 0 , 0, 0, 0, 0};
volatile long BUTTON0_PUSHTIME_START[] = { -1 , -1, -1, -1, -1, -1 , -1, -1, -1, -1};
volatile long BUTTON0_PUSHTIME[] = { -1 , -1, -1, -1, -1, -1 , -1, -1, -1, -1};

const int BUTTON1_X = A4;
const int BUTTON1_INH = 10;
volatile int BUTTON1_VALUES_LAST[] = { -1 , -1, -1, -1, -1, -1 , -1, -1, -1, -1};
volatile int BUTTON1_VALUES_LAST_SEND[] = { -1 , -1, -1, -1, -1, -1 , -1, -1, -1, -1};
volatile int BUTTON1_VALUES[] = { 0 , 0, 0, 0, 0, 0 , 0, 0, 0, 0};
volatile long BUTTON1_PUSHTIME_START[] = { -1 , -1, -1, -1, -1, -1 , -1, -1, -1, -1};
volatile long BUTTON1_PUSHTIME[] = { -1 , -1, -1, -1, -1, -1 , -1, -1, -1, -1};


#ifdef USE_SLIP_SERIAL
#include <SLIPEncodedUSBSerial.h>
SLIPEncodedUSBSerial SLIPSerial( SerialUSB );
#endif

IntervalTimer updateDisplayTimer;
IntervalTimer softPWMTimer;
Chrono sendOSC;
Chrono readInputsChrono;

MUX74HC4067 mux_pot1(POT1_INH, ADDR_A, ADDR_B, ADDR_C, ADDR_D);
MUX74HC4067 mux_pot0(POT0_INH, ADDR_A, ADDR_B, ADDR_C, ADDR_D);
MUX74HC4067 mux_fader(FADER_INH, ADDR_A, ADDR_B, ADDR_C, ADDR_D);
MUX74HC4067 mux_button0(BUTTON0_INH, ADDR_A, ADDR_B, ADDR_C, ADDR_D);
MUX74HC4067 mux_button1(BUTTON1_INH, ADDR_A, ADDR_B, ADDR_C, ADDR_D);


#ifdef USE_ETHERNET
EthernetUDP Udp;
#endif

SevSeg sevseg;

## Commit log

2021-01-29 pre STATE perfomance
    [NOMIDI_Controller_005_fix.brd]
2021-03-17 bom link
    [NOMIDI_Controller_005_fix.brd, NOMIDI_Controller_005_fix.sch]
2021-03-18 rename firemware
    [NOMIDI_Controller_001.brd, NOMIDI_Controller_001.sch, NOMIDI_Controller_002_nopulldown.brd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]
2021-03-24 readme + slipserial
    [NOMIDI_Controller_006_clean.brd, NOMIDI_Controller_006_clean.sch]

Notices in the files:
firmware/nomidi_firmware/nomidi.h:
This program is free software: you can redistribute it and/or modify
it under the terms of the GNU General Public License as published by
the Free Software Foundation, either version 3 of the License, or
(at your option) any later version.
